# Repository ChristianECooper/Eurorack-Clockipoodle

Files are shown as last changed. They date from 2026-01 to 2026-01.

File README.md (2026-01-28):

### Clockipoodle
Clockipoodle is a clock module designed for use in a Eurorack modular synthesizer.

It's based on an Arduino nano, driving a Darlington Array, the UI is:
- a 128x64 pixel SSD1306 display,
- a switched rotary encoder,
- 2 x momentary buttons
- 6 x 3.5mm standard jacks

As of version 1.1 it supports the following options:
1. Direct setting of BPM via a rotary encoder.
2. Indirect setting of the BPM, using the rotary encoder to set, then pressing the encoder to apply.
3. Four additional outputs labelled A through to D that can be a multuplied, divided, duplicate or a disabled copy of the main clock.
4. Tap to set BPM.
5. Adjustable pulse width.
6. Play/Pause.
7. Reset the various outputs to be in sync again.

There is also an unused input currenly labeled as 'CV IN' and and associated LED, which may become a Clock in or CV input that drives a parameter (or parameters) to be later defined.
The current design is limited to 0-5V so could only really increase the tempo, so the next iteration is likely to support -5 to +5v so that decreasing tempo from a CV input is an option.
In the meantime I'm considering using the CV input to adjust a swing component of the beat.

All input and output jacks are protected against over voltage and negative voltages for safety.

This is my first stab at a module design, comments are welcome.

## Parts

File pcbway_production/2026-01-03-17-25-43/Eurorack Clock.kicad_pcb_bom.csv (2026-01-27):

Designator | Quantity | Value | Footprint | Package | MPN | DNP | Mount_Type | Description | Sim.Pins
A1 | 1 | Arduino_Nano_v3.x | Arduino_Nano |  |  |  | tht | Arduino Nano v3.x
C1 | 1 | 0.1u | CP_Radial_D10.0mm_P2.50mm |  |  |  | tht | Polarized capacitor
D1, D10, D11, D12, D13, D14, D2, D5, D6, D7, D8, D9 | 12 | BAT43 | D_DO-35_SOD27_P2.54mm_Vertical_KathodeUp |  |  |  | tht | 30V 0.2A Small Signal Schottky Diode, DO-35
D15, D16, D17, D18, D19, D20 | 6 | LED | LED_D3.0mm_FlatTop |  |  |  | tht | Light emitting diode | 1=K 2=A
DS1 | 1 | ~ | SSD1306_0.96_I2C_Display |  |  |  | smt
J1 | 1 | Conn_01x10_Pin | PinHeader_1x10_P2.54mm_Vertical |  |  |  | tht | Generic connector, single row, 01x10, script generated
J10 | 1 | CLK/16 | Jack_3.5mm_QingPu_WQP-PJ398SM_Vertical_CircularHoles |  |  |  | tht | Audio Jack, 2 Poles (Mono / TS)
J11 | 1 | Conn_02x08_Row_Letter_Last | IDC-Header_2x08_P2.54mm_Vertical_Eurorack |  |  |  | tht | Generic connector, double row, 02x08, row letter last pin numbering scheme (pin number consists of a letter for the row and a number for the pin index in this row. 1a, ..., Na; 1b, ..., Nb)), script generated (kicad-library-utils/schlib/autogen/connector/)
J12 | 1 | Conn_01x02_Pin | PinHeader_1x02_P2.54mm_Vertical |  |  |  | tht | Generic connector, single row, 01x02, script generated
J13 | 1 | Conn_01x02_Socket | PinSocket_1x02_P2.54mm_Vertical |  |  |  | tht | Generic connector, single row, 01x02, script generated
J2 | 1 | Conn_01x08_Pin | PinHeader_1x08_P2.54mm_Vertical |  |  |  | tht | Generic connector, single row, 01x08, script generated
J3 | 1 | Clock In | Jack_3.5mm_QingPu_WQP-PJ398SM_Vertical_CircularHoles |  |  |  | tht | Audio Jack, 2 Poles (Mono / TS)
J4 | 1 | Conn_01x10_Socket | PinSocket_1x10_P2.54mm_Vertical |  |  |  | tht | Generic connector, single row, 01x10, script generated
J5 | 1 | Conn_01x08_Pin | PinSocket_1x08_P2.54mm_Vertical |  |  |  | tht | Generic connector, single row, 01x08, script generated
J6 | 1 | CLK | Jack_3.5mm_QingPu_WQP-PJ398SM_Vertical_CircularHoles |  |  |  | tht | Audio Jack, 2 Poles (Mono / TS)
J7 | 1 | CLK/2 | Jack_3.5mm_QingPu_WQP-PJ398SM_Vertical_CircularHoles |  |  |  | tht | Audio Jack, 2 Poles (Mono / TS)
J8 | 1 | CLK/4 | Jack_3.5mm_QingPu_WQP-PJ398SM_Vertical_CircularHoles |  |  |  | tht | Audio Jack, 2 Poles (Mono / TS)
J9 | 1 | CLK/8 | Jack_3.5mm_QingPu_WQP-PJ398SM_Vertical_CircularHoles |  |  |  | tht | Audio Jack, 2 Poles (Mono / TS)
R1 | 1 | 470R | R_Axial_DIN0204_L3.6mm_D1.6mm_P2.54mm_Vertical |  |  |  | tht | Resistor
R10, R11, R12, R13, R8, R9 | 6 | 100R | R_Axial_DIN0204_L3.6mm_D1.6mm_P2.54mm_Vertical |  |  |  | tht | Resistor
R2, R3, R4, R5, R6 | 5 | 1K | R_Axial_DIN0204_L3.6mm_D1.6mm_P2.54mm_Vertical |  |  |  | tht | Resistor
REF_Reset, REF_Run, Reset, Run | 4 | PinHeader_1x02_P2.54mm_Vertical | PinHeader_1x02_P2.54mm_Vertical |  |  |  | tht
REF_Stand1, REF_Stand1A, REF_Stand2, REF_Stand2A | 4 | PinHeader_1x01_P2.54mm_Vertical | PinHeader_1x01_P2.54mm_Vertical |  |  |  | tht
SW1 | 1 | RotaryEncoder_DualWithSwitch | RotaryEncoder_Vertical_H25mm_Dual_PushButton |  |  |  | smt | Rotary encoder, dual channel, incremental quadrate outputs, with switch
SW2 | 1 | Run/Stop | SW_PUSH_6mm_H4.3mm |  |  |  | tht | Single Pole Single Throw (SPST) switch
SW3 | 1 | Reset | SW_PUSH_6mm_H4.3mm |  |  |  | tht | Single Pole Single Throw (SPST) switch
U1 | 1 | ULN2003 | DIP-16_W7.62mm_Socket |  |  |  | tht | High Voltage, High Current Darlington Transistor Arrays, SOIC16/SOIC16W/DIP16/TSSOP16
U6 | 1 | L7805 | TO-220-3_Vertical |  |  |  | tht | Positive 1.5A 35V Linear Regulator, Fixed Output 5V, TO-220/TO-263/TO-252

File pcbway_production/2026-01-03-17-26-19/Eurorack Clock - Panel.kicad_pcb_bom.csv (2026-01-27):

Designator | Quantity | Value | Footprint | Package | MPN | DNP | Mount_Type | Sim.Pins
6H | 1 | MountingHoles_6H_Panel | MountingHoles_6H_Panel |  |  |  | smt
D15X, D16X, D17X, D18X, D19X, D20X | 6 | LED | MountingHole_3.1mm_LED_D3.0mm_FlatTop |  |  |  | tht | 1=K 2=A
DS1X | 1 | ~ | MoutingHole_24x12mm_SSD1306_0.96_I2C_Display |  |  |  | smt
J10X | 1 | CLK/16 | MountingHole_6.0mm_Jack_3.5mm_QingPu_Vertical |  |  |  | tht
J3X | 1 | Clock In | MountingHole_6.0mm_Jack_3.5mm_QingPu_Vertical |  |  |  | tht
J6X | 1 | CLK | MountingHole_6.0mm_Jack_3.5mm_QingPu_Vertical |  |  |  | tht
J7X | 1 | CLK/2 | MountingHole_6.0mm_Jack_3.5mm_QingPu_Vertical |  |  |  | tht
J8X | 1 | CLK/4 | MountingHole_6.0mm_Jack_3.5mm_QingPu_Vertical |  |  |  | tht
J9X | 1 | CLK/8 | MountingHole_6.0mm_Jack_3.5mm_QingPu_Vertical |  |  |  | tht
SW1X | 1 | RotaryEncoder_DualWithSwitch | MountingHole_7.1mm_RotaryEncoder_Vertical_H25mm_Dual_PushButton |  |  |  | smt
SW2X | 1 | Run/Stop | MountingHole_8.1mm_SW_PUSH_6x6mm |  |  |  | tht
SW3X | 1 | Reset | MountingHole_8.1mm_SW_PUSH_6x6mm |  |  |  | tht

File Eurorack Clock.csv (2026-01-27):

Reference | Qty | Value | DNP | Exclude from BOM | Exclude from Board | Footprint | Datasheet
A1 | 1 | Arduino_Nano_v3.x |  |  |  | Module:Arduino_Nano | http://www.mouser.com/pdfdocs/Gravitech_Arduino_Nano3_0.pdf
C1 | 1 | 0.1u |  |  |  | Capacitor_THT:CP_Radial_D10.0mm_P2.50mm | ~
D1,D2,D5,D6,D7,D8,D9,D10,D11,D12,D13,D14 | 12 | BAT43 |  |  |  | Diode_THT:D_DO-35_SOD27_P2.54mm_Vertical_KathodeUp | http://www.vishay.com/docs/85660/bat42.pdf
D15,D16,D17,D18,D19,D20 | 6 | LED |  |  |  | LED_THT:LED_D3.0mm_FlatTop | ~
DS1 | 1 | ~ |  |  |  | Displays:SSD1306_0.96_I2C_Display
J1 | 1 | Conn_01x10_Pin |  |  |  | Connector_PinHeader_2.54mm:PinHeader_1x10_P2.54mm_Vertical | ~
J2 | 1 | Conn_01x08_Pin |  |  |  | Connector_PinHeader_2.54mm:PinHeader_1x08_P2.54mm_Vertical | ~
J3 | 1 | Clock In |  |  |  | Connector_Audio:Jack_3.5mm_QingPu_WQP-PJ398SM_Vertical_CircularHoles | ~
J4 | 1 | Conn_01x10_Socket |  |  |  | Connector_PinSocket_2.54mm:PinSocket_1x10_P2.54mm_Vertical | ~
J5 | 1 | Conn_01x08_Pin |  |  |  | Connector_PinSocket_2.54mm:PinSocket_1x08_P2.54mm_Vertical | ~
J6 | 1 | CLK |  |  |  | Connector_Audio:Jack_3.5mm_QingPu_WQP-PJ398SM_Vertical_CircularHoles | ~
J7 | 1 | CLK/2 |  |  |  | Connector_Audio:Jack_3.5mm_QingPu_WQP-PJ398SM_Vertical_CircularHoles | ~
J8 | 1 | CLK/4 |  |  |  | Connector_Audio:Jack_3.5mm_QingPu_WQP-PJ398SM_Vertical_CircularHoles | ~
J9 | 1 | CLK/8 |  |  |  | Connector_Audio:Jack_3.5mm_QingPu_WQP-PJ398SM_Vertical_CircularHoles | ~
J10 | 1 | CLK/16 |  |  |  | Connector_Audio:Jack_3.5mm_QingPu_WQP-PJ398SM_Vertical_CircularHoles | ~
J11 | 1 | Conn_02x08_Row_Letter_Last |  |  |  | Eurorack Switches:IDC-Header_2x08_P2.54mm_Vertical_Eurorack | ~
J12 | 1 | Conn_01x02_Pin |  |  |  | Connector_PinHeader_2.54mm:PinHeader_1x02_P2.54mm_Vertical | ~
J13 | 1 | Conn_01x02_Socket |  |  |  | Connector_PinSocket_2.54mm:PinSocket_1x02_P2.54mm_Vertical | ~
JP1 | 1 | 5v/12v power source |  | Excluded from BOM |  | Connector_PinHeader_2.54mm:PinHeader_1x03_P2.54mm_Vertical | ~
JP2 | 1 | 5V Source |  | Excluded from BOM |  | Jumper:SolderJumper-2_P1.3mm_Open_Pad1.0x1.5mm | ~
JP3 | 1 | 12V Source |  | Excluded from BOM |  | Jumper:SolderJumper-2_P1.3mm_Open_Pad1.0x1.5mm | ~
R1 | 1 | 470R |  |  |  | Resistor_THT:R_Axial_DIN0204_L3.6mm_D1.6mm_P2.54mm_Vertical | ~
R2,R3,R4,R5,R6 | 5 | 1K |  |  |  | Resistor_THT:R_Axial_DIN0204_L3.6mm_D1.6mm_P2.54mm_Vertical | ~
R8,R9,R10,R11,R12,R13 | 6 | 100R |  |  |  | Resistor_THT:R_Axial_DIN0204_L3.6mm_D1.6mm_P2.54mm_Vertical | ~
SW1 | 1 | RotaryEncoder_DualWithSwitch |  |  |  | Rotary Encoders:RotaryEncoder_Vertical_H25mm_Dual_PushButton | ~
SW2 | 1 | Run/Stop |  |  |  | Button_Switch_THT:SW_PUSH_6mm_H4.3mm | ~
SW3 | 1 | Reset |  |  |  | Button_Switch_THT:SW_PUSH_6mm_H4.3mm | ~
U1 | 1 | ULN2003 |  |  |  | Package_DIP:DIP-16_W7.62mm_Socket | http://www.ti.com/lit/ds/symlink/uln2003a.pdf
U6 | 1 | L7805 |  |  |  | Package_TO_SOT_THT:TO-220-3_Vertical | http://www.st.com/content/ccc/resource/technical/document/datasheet/41/4f/b3/b0/12/d4/47/88/CD00000444.pdf/files/CD00000444.pdf/jcr:content/translations/en.CD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

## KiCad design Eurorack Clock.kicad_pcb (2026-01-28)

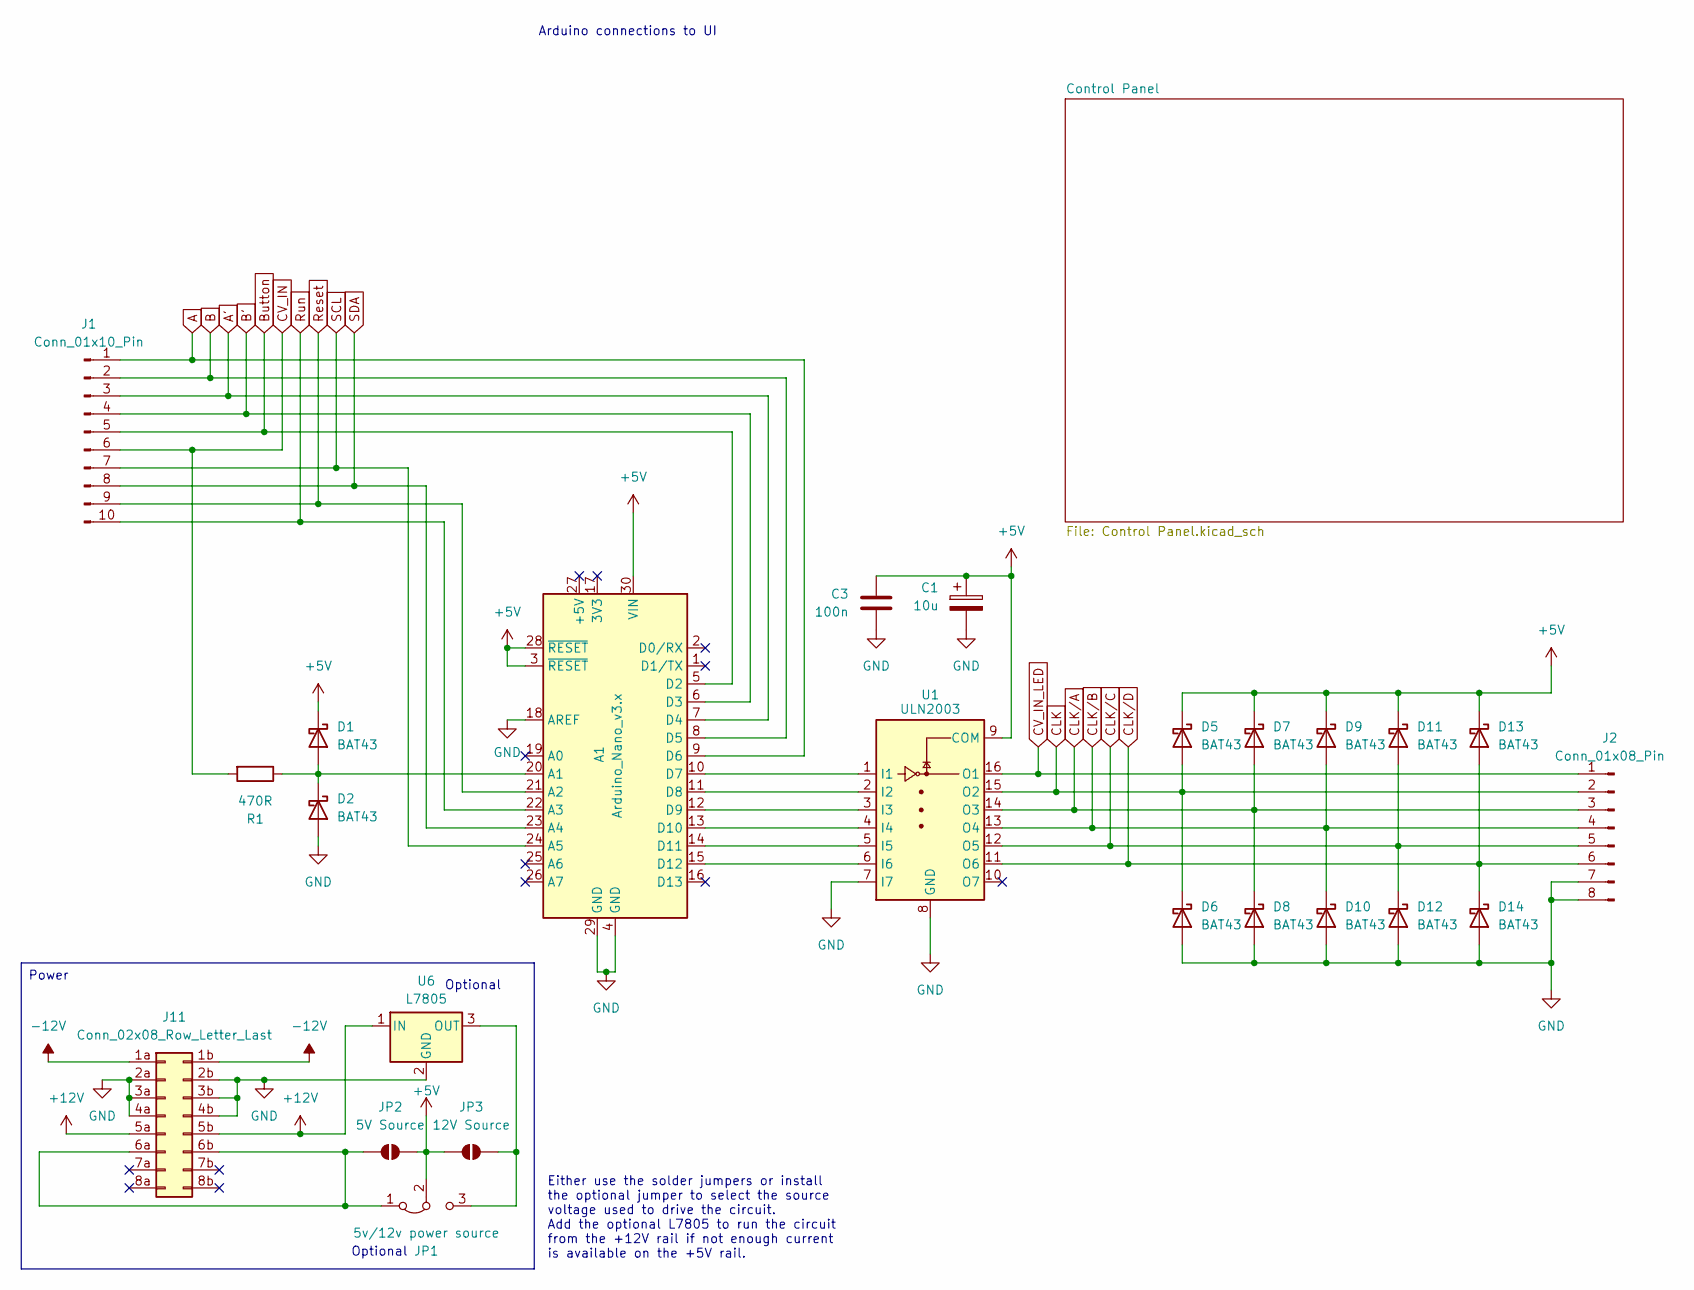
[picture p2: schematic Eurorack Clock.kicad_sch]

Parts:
A1: Arduino_Nano_v3.x; Arduino_Nano
C1: 10u; CP_Radial_D5.0mm_P2.50mm
C3: 100n; C_Disc_D4.7mm_W2.5mm_P5.00mm
D1, D2, D5, D6, D7, D8, D9, D10, D11, D12, D13, D14: BAT43; D_DO-35_SOD27_P2.54mm_Vertical_KathodeUp
J1: Conn_01x10_Pin; PinHeader_1x10_P2.54mm_Vertical
J2: Conn_01x08_Pin; PinHeader_1x08_P2.54mm_Vertical
J11: Conn_02x08_Row_Letter_Last; IDC-Header_2x08_P2.54mm_Vertical_Eurorack
JP1: 5v/12v power source; PinHeader_1x03_P2.54mm_Vertical
JP2: 5V Source; SolderJumper-2_P1.3mm_Open_Pad1.0x1.5mm
JP3: 12V Source; SolderJumper-2_P1.3mm_Open_Pad1.0x1.5mm
R1: 470R; R_Axial_DIN0204_L3.6mm_D1.6mm_P2.54mm_Vertical
U1: ULN2003; DIP-16_W7.62mm_Socket
U6: L7805; TO-220-3_Vertical

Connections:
+5V: A1.3 (~RESET), A1.28 (~RESET), A1.30 (VIN), C1.1, C3.1, D1.1 (K), D5.1 (K), D7.1 (K), D9.1 (K), D11.1 (K), D13.1 (K), JP1.2 (C), JP2.2 (B), JP3.1 (A), U1.9 (COM); also elsewhere on the board
+12V: J11.5a, J11.5b, U6.1 (IN)
-12V: J11.1a, J11.1b
A: A1.9 (D6), J1.1; also elsewhere on the board
A': A1.7 (D4), J1.3; also elsewhere on the board
B: A1.8 (D5), J1.2; also elsewhere on the board
B': A1.6 (D3), J1.4; also elsewhere on the board
Button: A1.5 (D2), J1.5; also elsewhere on the board
CLK: D5.2 (A), D6.1 (K), J2.2, U1.15 (O2); also elsewhere on the board
CLK/A: D7.2 (A), D8.1 (K), J2.3, U1.14 (O3); also elsewhere on the board
CLK/B: D9.2 (A), D10.1 (K), J2.4, U1.13 (O4); also elsewhere on the board
CLK/C: D11.2 (A), D12.1 (K), J2.5, U1.12 (O5); also elsewhere on the board
CLK/D: D13.2 (A), D14.1 (K), J2.6, U1.11 (O6); also elsewhere on the board
CV_IN: J1.6, R1.2; also elsewhere on the board
CV_IN_LED: J2.1, U1.16 (O1); also elsewhere on the board
GND: A1.4 (GND), A1.18 (AREF), A1.29 (GND), C1.2, C3.2, D2.2 (A), D6.2 (A), D8.2 (A), D10.2 (A), D12.2 (A), D14.2 (A), J2.7, J2.8, J11.2a, J11.2b, J11.3a, J11.3b, J11.4a, J11.4b, U1.7 (I7), U1.8 (GND), U6.2 (GND); also elsewhere on the board
unnamed: A1.20 (A1), D1.2 (A), D2.1 (K), R1.1
unnamed: A1.10 (D7), U1.1 (I1)
unnamed: A1.11 (D8), U1.2 (I2)
unnamed: A1.12 (D9), U1.3 (I3)
unnamed: A1.13 (D10), U1.4 (I4)
unnamed: A1.14 (D11), U1.5 (I5)
unnamed: A1.15 (D12), U1.6 (I6)
unnamed: J11.6a, J11.6b, JP1.1 (A), JP2.1 (A)
unnamed: JP1.3 (B), JP3.2 (B), U6.3 (OUT)
Reset: A1.21 (A2), J1.9; also elsewhere on the board
Run: A1.22 (A3), J1.10; also elsewhere on the board
SCL: A1.24 (A5), J1.7; also elsewhere on the board
SDA: A1.23 (A4), J1.8; also elsewhere on the board

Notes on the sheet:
Either use the solder jumpers or install the optional jumper to select the source voltage used to drive the circuit. Add the optional L7805 to run the circuit from the +12V rail if not enough current is available on the +5V rail.
Optional
Arduino connections to UI
Power

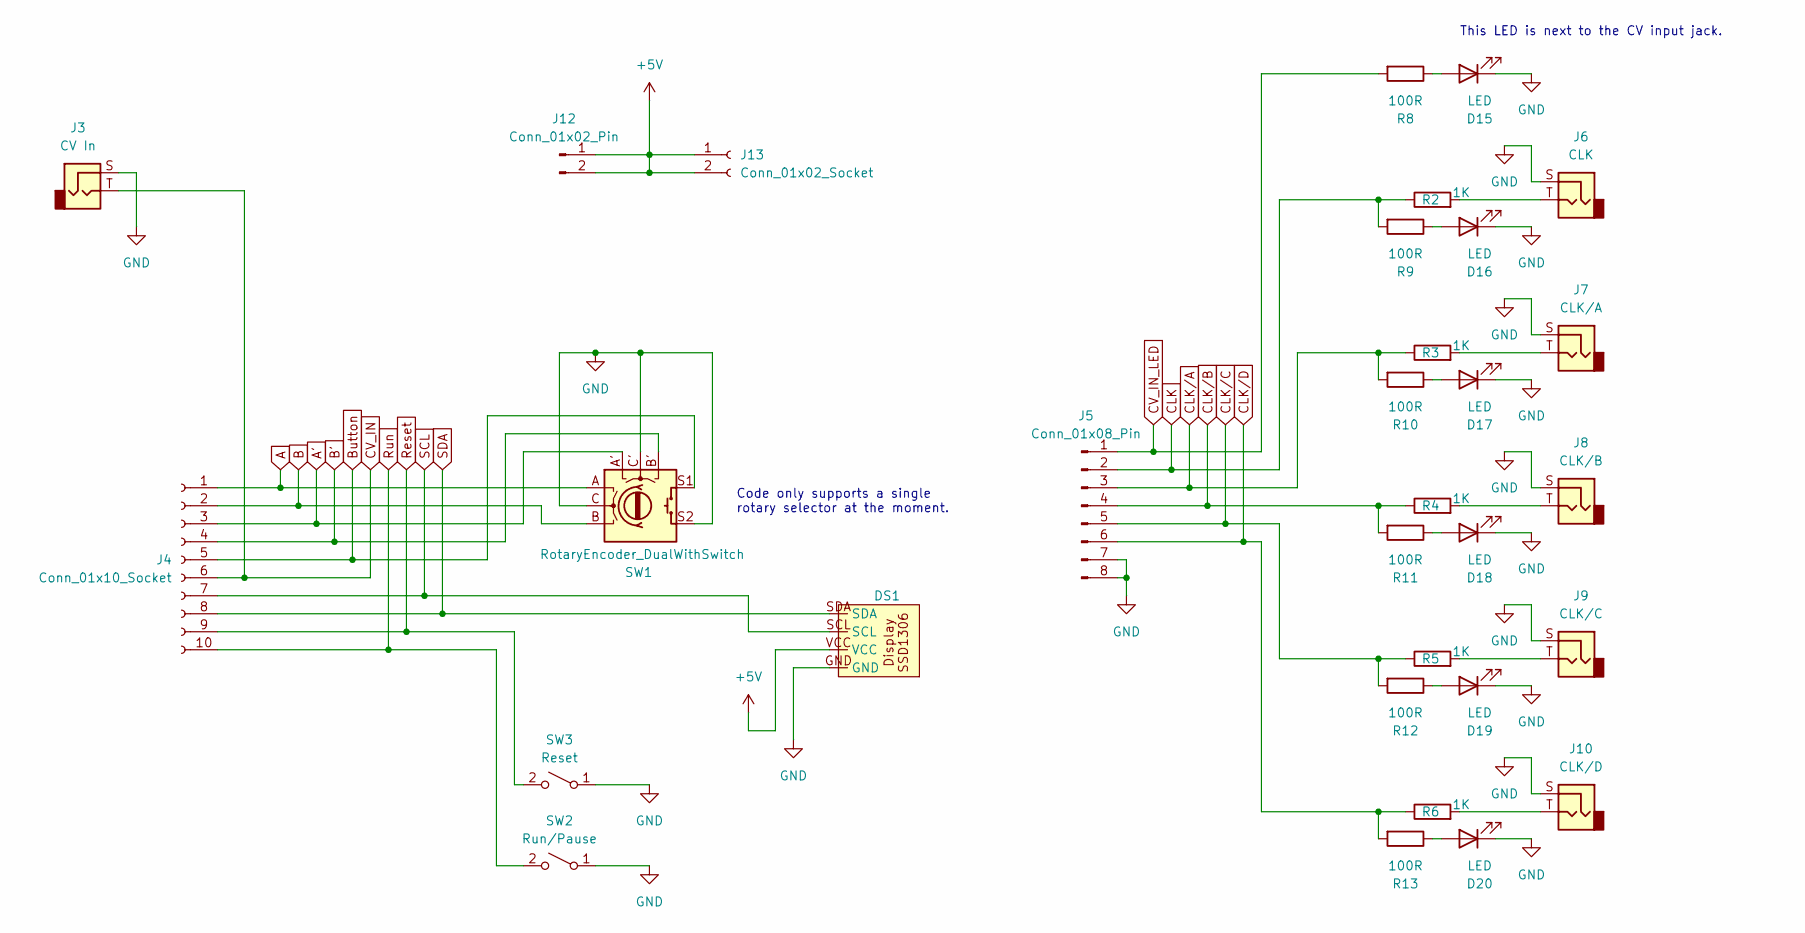
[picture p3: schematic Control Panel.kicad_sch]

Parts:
D15, D16, D17, D18, D19, D20: LED; LED_D3.0mm_FlatTop
DS1: SSD1306_0.96_I2C_Display
J3: CV In; Jack_3.5mm_QingPu_WQP-PJ398SM_Vertical_CircularHoles
J4: Conn_01x10_Socket; PinSocket_1x10_P2.54mm_Vertical
J5: Conn_01x08_Pin; PinSocket_1x08_P2.54mm_Vertical
J6: CLK; Jack_3.5mm_QingPu_WQP-PJ398SM_Vertical_CircularHoles
J7: CLK/A; Jack_3.5mm_QingPu_WQP-PJ398SM_Vertical_CircularHoles
J8: CLK/B; Jack_3.5mm_QingPu_WQP-PJ398SM_Vertical_CircularHoles
J9: CLK/C; Jack_3.5mm_QingPu_WQP-PJ398SM_Vertical_CircularHoles
J10: CLK/D; Jack_3.5mm_QingPu_WQP-PJ398SM_Vertical_CircularHoles
J12: Conn_01x02_Pin; PinHeader_1x02_P2.54mm_Vertical
J13: Conn_01x02_Socket; PinSocket_1x02_P2.54mm_Vertical
R2, R3, R4, R5, R6: 1K; R_Axial_DIN0204_L3.6mm_D1.6mm_P2.54mm_Vertical
R8, R9, R10, R11, R12, R13: 100R; R_Axial_DIN0204_L3.6mm_D1.6mm_P2.54mm_Vertical
SW1: RotaryEncoder_DualWithSwitch; RotaryEncoder_Vertical_H25mm_Dual_PushButton
SW2: Run/Pause; SW_PUSH_6mm_H4.3mm
SW3: Reset; SW_PUSH_6mm_H4.3mm

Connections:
+5V: DS1.VCC, J12.1, J12.2, J13.1, J13.2; also elsewhere on the board
A: J4.1, SW1.A; also elsewhere on the board
A': J4.3, SW1.A'; also elsewhere on the board
B: J4.2, SW1.B; also elsewhere on the board
B': J4.4, SW1.B'; also elsewhere on the board
Button: J4.5, SW1.S1; also elsewhere on the board
CLK: J5.2, R2.1, R9.2; also elsewhere on the board
CLK/A: J5.3, R3.1, R10.2; also elsewhere on the board
CLK/B: J5.4, R4.1, R11.2; also elsewhere on the board
CLK/C: J5.5, R5.1, R12.2; also elsewhere on the board
CLK/D: J5.6, R6.1, R13.2; also elsewhere on the board
CV_IN: J3.T, J4.6; also elsewhere on the board
CV_IN_LED: J5.1, R8.2; also elsewhere on the board
GND: D15.1 (K), D16.1 (K), D17.1 (K), D18.1 (K), D19.1 (K), D20.1 (K), DS1.GND, J3.S, J5.7, J5.8, J6.S, J7.S, J8.S, J9.S, J10.S, SW1.C, SW1.C', SW1.S2, SW2.1 (A), SW3.1 (A); also elsewhere on the board
unnamed: D15.2 (A), R8.1
unnamed: D16.2 (A), R9.1
unnamed: D17.2 (A), R10.1
unnamed: D18.2 (A), R11.1
unnamed: D19.2 (A), R12.1
unnamed: D20.2 (A), R13.1
unnamed: J6.T, R2.2
unnamed: J7.T, R3.2
unnamed: J8.T, R4.2
unnamed: J9.T, R5.2
unnamed: J10.T, R6.2
Reset: J4.9, SW3.2 (B); also elsewhere on the board
Run: J4.10, SW2.2 (B); also elsewhere on the board
SCL: DS1.SCL, J4.7; also elsewhere on the board
SDA: DS1.SDA, J4.8; also elsewhere on the board

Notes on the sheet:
Code only supports a single rotary selector at the moment.
This LED is next to the CV input jack.

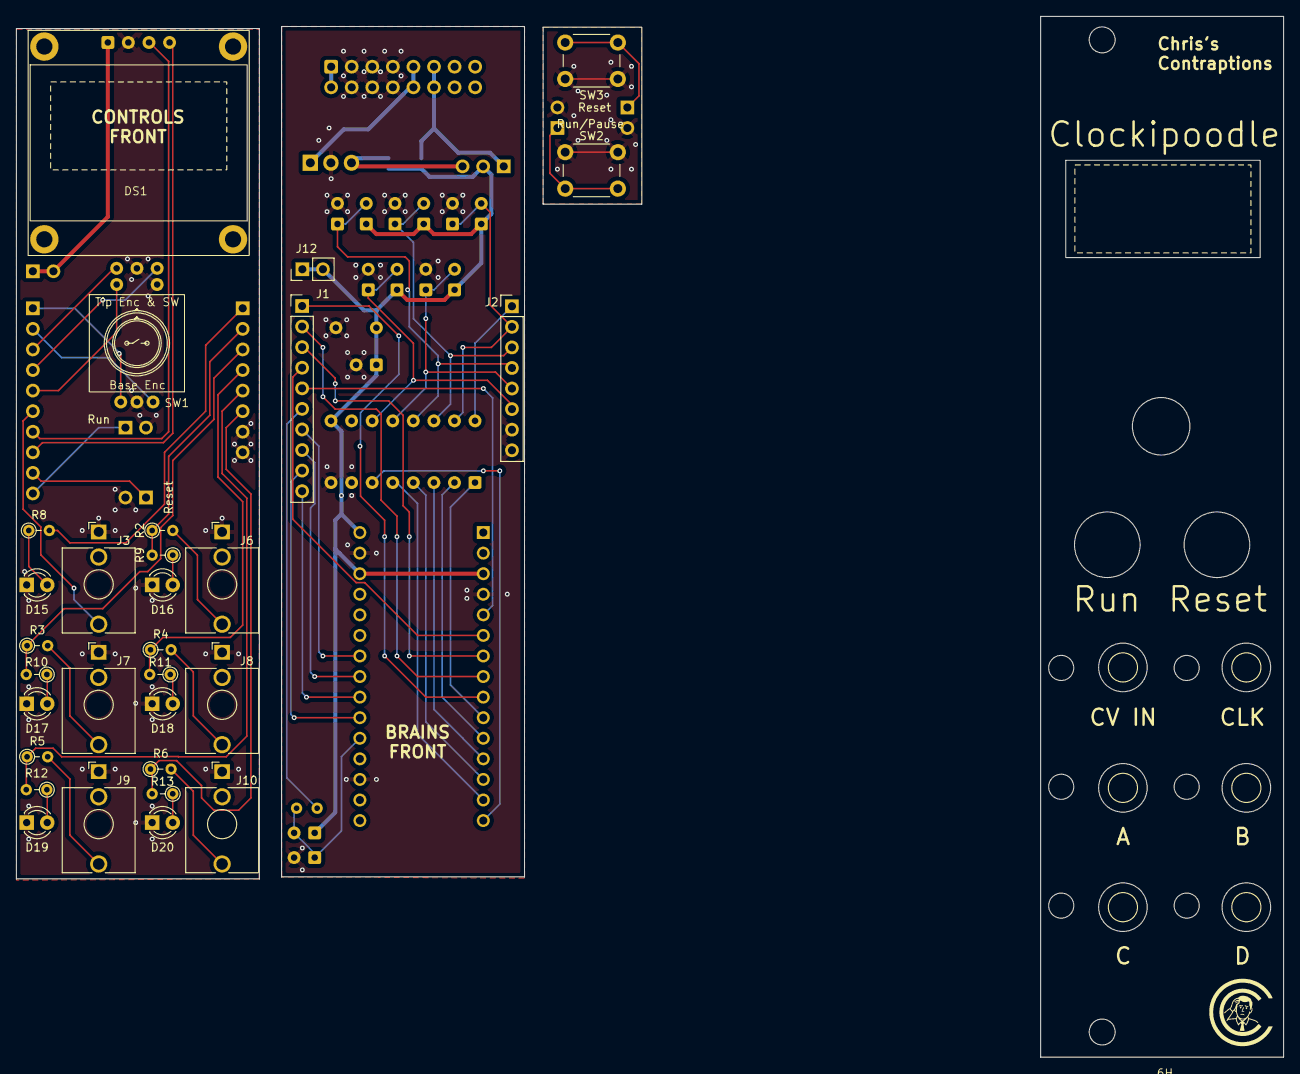
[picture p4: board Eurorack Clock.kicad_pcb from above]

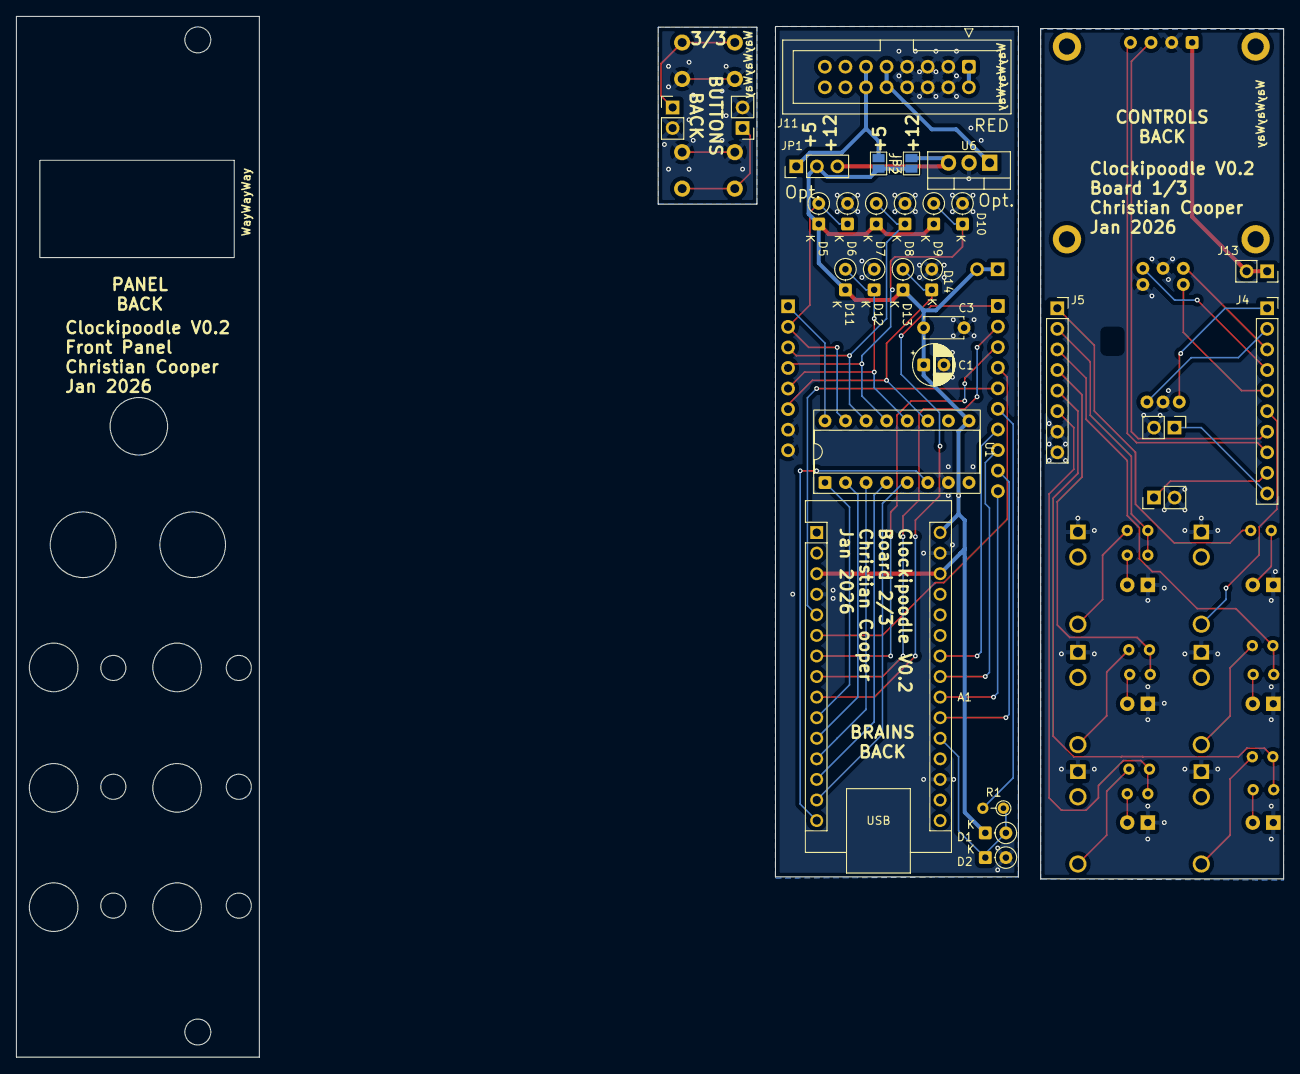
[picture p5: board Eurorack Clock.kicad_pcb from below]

Board: 2 copper layers, 156.5 x 128.5 mm, 77 parts (29 on the bottom side), 40 nets.

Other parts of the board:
6H: MountingHoles_6H_Panel
D15X, D16X, D17X, D18X, D19X, D20X: LED; MountingHole_3.1mm_LED_D3.0mm_FlatTop
DS1X: MoutingHole_24x12mm_SSD1306_0.96_I2C_Display
J3X: CV IN; MountingHole_6.0mm_Jack_3.5mm_QingPu_Vertical
J6X: CLK; MountingHole_6.0mm_Jack_3.5mm_QingPu_Vertical
J7X: CLK/2; MountingHole_6.0mm_Jack_3.5mm_QingPu_Vertical
J8X: CLK/4; MountingHole_6.0mm_Jack_3.5mm_QingPu_Vertical
J9X: CLK/8; MountingHole_6.0mm_Jack_3.5mm_QingPu_Vertical
J10X: CLK/16; MountingHole_6.0mm_Jack_3.5mm_QingPu_Vertical
LOGO***: LOGO; cc_logo
REF_Reset: PinHeader_1x02_P2.54mm_Vertical
REF_Run: PinHeader_1x02_P2.54mm_Vertical
Reset: PinHeader_1x02_P2.54mm_Vertical
Run: PinHeader_1x02_P2.54mm_Vertical
SW1X: RotaryEncoder_DualWithSwitch; MountingHole_7.1mm_RotaryEncoder_Vertical_H25mm_Dual_PushBu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
SW2X: Run/Stop; MountingHole_8.1mm_SW_PUSH_6x6mm
SW3X: Reset; MountingHole_8.1mm_SW_PUSH_6x6mm

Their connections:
GND: REF_Reset.2, REF_Run.2, Reset.2, Run.2; also elsewhere on the board
Reset: REF_Reset.1, Reset.1; also elsewhere on the board
Run: REF_Run.1, Run.1; also elsewhere on the board

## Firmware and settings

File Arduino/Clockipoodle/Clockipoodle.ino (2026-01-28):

/*
TODO:
-- 0. Fix timing bugs!
-- 1. Setting pulse width
-- 2. Setting for direct BPM mode - no click to apply new BPM
-- 3. Reset button to revert in menu system
-- 4. Display channel information on home screen
-- 5. Display 'BPM' on home screen and align big text at 2 chars
-- 6. Fast rotation increments step size on bpm selection
-- 7. Implement start/stop button
-- 8. Implement facory reset
9. Custom font?
10. Clock in & LED
-- 11. Tap to set BPM
*/

// Display
#include <SPI.h>
#include <Wire.h>
#include <Adafruit_GFX.h>
#include <Adafruit_SSD1306.h>

#include <EEPROM.h>

//////////////////////////////////////////////////////////////////////
// Logging
//////////////////////////////////////////////////////////////////////
//***************************************************************
#define DEBUG  // if this line is NOT commented, LO and LOG macros will be included in the sketch

#ifdef DEBUG
#define LO(args...)  Serial.print(args)
#define LOG(args...)  Serial.println(args)

#else

#define LO(args...)
#define LOG(args...)
#endif


//////////////////////////////////////////////////////////////////////
// Constants
//////////////////////////////////////////////////////////////////////
#define VERSION "V1.1"

// IO state management (internal pull-ups used, so values are inverted)
#define PRESSED LOW
#define RELEASED HIGH

// EEPROM
// Magic number for EEPROM initialisation detection
#define MAGIC_NUMBER 0xCC
#define EEPROM_BASE_ADDRESS 16

// Display
#define SCREEN_WIDTH 128 // OLED display width, in pixels
#define SCREEN_HEIGHT 64 // OLED display height, in pixels
#define OLED_RESET     -1 // Reset pin # (or -1 if sharing Arduino reset pin)
#define SCREEN_ADDRESS 0x3C ///< See datasheet for Address; 0x3D for 128x64, 0x3C for 128x32

#define CHAR_HEIGHT 8
#define CHAR_WIDTH 8

// --- Inputs ---
// Rotary encoder
#define ROTARY_PINA	6
#define ROTARY_PINB	5
#define BUTTON_PIN	2

#define CLOCK_IN_PIN A1
#define RESET_PIN    A2
#define RUN_PIN      A3

// --- Outputs ---
#define CLOCK_IN_LED_PIN   7
#define CLOCK_PIN          8
#define CLOCK_CUSTOM_1_PIN 9
#define CLOCK_CUSTOM_2_PIN 10
#define CLOCK_CUSTOM_3_PIN 11
#define CLOCK_CUSTOM_4_PIN 12

// Clock specification
#define DEFAULT_PULSE_WIDTH 10 // ms

// Update mode
#define DEFAULT_DIRECT_BPM_MODE false

// Config layout
#define CONFIG_PULSE_WIDTH_LINE 4
#define CONFIG_DIRECT_BPM_LINE 5
#define CONFIG_TAP_LINE 6
#define CONFIG_RETURN_LINE 7

//////////////////////////////////////////////////////////////////////
// Structs
//////////////////////////////////////////////////////////////////////
struct customClock{
  char clockType; // Limited to 'X'=OFF, '/'=DIV, '='=DUPE, '*'=MUL
  int clockCount; // Indicates factor used for '*' and '/' clock types
};

//////////////////////////////////////////////////////////////////////
// Enums
//////////////////////////////////////////////////////////////////////
// State machine
// State for main overall mode
enum DisplayMode{RUN, CONFIG, TAP};
// Sub-states for CONFIG mode
enum ConfigMode{SELECT_LINE, SELECT_VALUE, UPDATE_PULSE_WIDTH, UPDATE_DIRECT_BPM_MODE, UPDATE_VALUE};
// Sub-sub-states for CONFIG/SELECT_VALUE
enum ConfigOption{FUNCTION, VALUE, LINE_RETURN};

// Lines visible on the config screen
enum ConfigLine{A, B, C, D, PULSE_WIDTH, BPM_DIRECT, TAP_MODE, RETURN};

//////////////////////////////////////////////////////////////////////
// Constants
//////////////////////////////////////////////////////////////////////
const int CUSTOM_CLOCK_PINS[] = {CLOCK_CUSTOM_1_PIN, CLOCK_CUSTOM_2_PIN, CLOCK_CUSTOM_3_PIN, CLOCK_CUSTOM_4_PIN};
const char CHANNEL_NAMES[] = "ABCD";
const int MIN_BPM = 40;
const int MAX_BPM = 260;

//////////////////////////////////////////////////////////////////////
// Variables
//////////////////////////////////////////////////////////////////////
// Construct display
Adafruit_SSD1306 display(SCREEN_WIDTH, SCREEN_HEIGHT, &Wire, OLED_RESET);

// Live config
bool directBpmMode = DEFAULT_DIRECT_BPM_MODE;
int pulseWidth = DEFAULT_PULSE_WIDTH;
customClock customClocks[] = {
  {'/', 4},
  {'/', 2},
  {'*', 2},
  {'*', 4},
};

// All on internal pull up resistors
bool rotaryAState = RELEASED;
bool rotaryBState = RELEASED;
bool rotaryButtonState = RELEASED;
bool resetState = RELEASED;
bool runState = RELEASED;

// State change flags
bool rotaryAStateUpdated = false;
bool rotaryBStateUpdated = false;
bool rotaryButtonStateUpdated = false;
bool resetStateUpdated = false;
bool runStateUpdated = false;

// State change detection
bool lastRotaryAState = RELEASED;
bool lastRotaryButtonState = RELEASED;
bool lastResetState = RELEASED;
bool lastRunState = RELEASED;

// BPM management
int bpm = 120;
int nextBpm = bpm;

// Event management
// Tracker of current beat in main clock for DIV cycles
volatile unsigned long tick = 0;
volatile unsigned long now = millis();
volatile unsigned long mainClockDelayMs = (long) (60.0 / bpm * 1000);
volatile unsigned long nextMainClockStart = now + mainClockDelayMs;
volatile unsigned long nextMainClockFinish = nextMainClockStart + pulseWidth;

bool customClockEnabled[] = {0, 0, 0, 0};
volatile unsigned long customClockDelay[] = {0, 0, 0, 0};
volatile unsigned long nextCustomClockStart[] = {0, 0, 0, 0};
volatile unsigned long nextCustomClockFinish[] = {0, 0, 0, 0};

// Tap mode, record of timestamps for taps
long taps[] = {0, 0, 0, 0};

// Start/Stop state
bool running = true;

// UI
bool updateDisplay = true;
// Default starting position of state machine
DisplayMode displayMode = RUN;

// UI - Config screen tracking
ConfigMode configMode = SELECT_LINE; 
ConfigLine configLine = A;
ConfigOption configOption = FUNCTION;
bool configOptionSelected = false;

//////////////////////////////////////////////////////////////////////
// Utility functions
//////////////////////////////////////////////////////////////////////
/**
  A version of constrain that wraps values around if they exceed the limits
*/
static byte wrap(int value, byte low, byte high) {
  if (value < low) return high;
  if (value > high) return low;
  return value;
}

//////////////////////////////////////////////////////////////////////
// Event functions
//////////////////////////////////////////////////////////////////////
/**
  Convert BPM and various custom clock mutiplies to durations in milliseconds
*/
static void calculateAllClockDelays() {
  mainClockDelayMs = (long) (60.0 / bpm * 1000.0);
  for (int i=0; i < 4; i++) {
    if (customClocks[i].clockType == '/') {
      customClockDelay[i] = mainClockDelayMs * customClocks[i].clockCount;
    } else if (customClocks[i].clockType == '*') {
      customClockDelay[i] = (long) (mainClockDelayMs / customClocks[i].clockCount);
    } else {
      // Not enabled
      customClockDelay[i] = 0;
    }
  }
}

/**
  Set the next start time for any of the clocks.
  If allClocks is false, then customCLockIndex of -1 means main clock
  If initialising is true all the clocks are reset to start from now
  If restarting is true (only valid for custom clocks), this indicates that a clock has moved out of its OFF state and is now running again
*/
static void updateNextStartTime(bool allClocks=false, int customClockIndex=-1, bool initialising=false, bool restarting=false) {
  if (initialising) {
    // Set all clocks to trigger now, except DIV ones
    nextMainClockStart = now;
    for (byte i; i < 4; i++) {
      if (customClockEnabled[i]) {
        nextCustomClockStart[i] = nextMainClockStart; 
      }
      if (customClocks[i].clockType == '/') {
        nextCustomClockStart[i] += customClockDelay[i];
      }
    }
  }

  if (allClocks) {
    // Move all expired clock start times forward
    if (now > nextMainClockStart) {
      // Main clock
      nextMainClockStart += mainClockDelayMs;
    }
    for (byte i; i < 4; i++) {
      // Custom clocks
      if (customClockEnabled[i] && now > nextCustomClockStart[i]) {
        if (customClocks[i].clockType == '=' || customClocks[i].clockType == '*') {
          nextCustomClockStart[i] = nextMainClockStart; 
        } else {
          nextCustomClockStart[i] += customClockDelay[i]; 
        }
      }
    }

  } else {
    // Move a specific clock forward
    if (customClockIndex == -1) {
      // Main clock
      nextMainClockStart += mainClockDelayMs;
    } else {
      // Custom clock
      nextCustomClockStart[customClockIndex] += customClockDelay[customClockIndex];
      if (restarting) {
        nextCustomClockStart[customClockIndex] = nextMainClockStart + customClockDelay[customClockIndex];
        if (customClocks[customClockIndex].clockType == '/') {
          // Account for changes during the sequence.
          // E.g.: Post tick 3 of 4 when a DIV 4 is enabled, Remove the delay of the first 3 ticks from out next start.
          byte missedTicks = tick % customClocks[customClockIndex].clockCount;
          nextCustomClockStart[customClockIndex] -= missedTicks * mainClockDelayMs;
        }
      }
    }
  }
}

/**
  Shift the finish time for a puls on a clock
  If allClocks is false, then customCLockIndex of -1 means main clock
  If initialising is true all the clocks are reset to current start time plus pulse width
*/
static void updateNextFinishTime(bool allClocks=false, int customClockIndex=-1, bool initialising=false) {
  if (initialising || allClocks) {
    // Set all active clock's finish times
    nextMainClockFinish = nextMainClockStart + pulseWidth;
    for (byte i; i < 4; i++) {
      nextCustomClockFinish[i] = nextCustomClockStart[i] + pulseWidth; 
    }
  } else if (customClockIndex == -1) {
    // Update main clock
    nextMainClockFinish = nextMainClockStart + pulseWidth;
  } else {
    // Update selected custom clock
    nextCustomClockFinish[customClockIndex] = nextCustomClockStart[customClockIndex] + pulseWidth;
  }
}

//////////////////////////////////////////////////////////////////////
// UI drawing functions
//////////////////////////////////////////////////////////////////////
static void drawTriangle(byte rowOffset, byte colOffset, bool filled = false) {
  byte width = 7;
  byte height = 6;
  if (filled) {
    display.fillTriangle(
      colOffset, rowOffset, 
      colOffset + width, 4 + rowOffset, 
      colOffset, 8 + rowOffset, 
      SSD1306_WHITE
    );
  } else {
    display.drawTriangle(
      colOffset, rowOffset, 
      colOffset + width, 4 + rowOffset, 
      colOffset, 8 + rowOffset, 
      SSD1306_WHITE
    );
  }
}

static void drawReturnArrow(byte rowOffset, byte colOffset) {
  display.drawLine(
    colOffset, rowOffset, 
    colOffset, rowOffset + 4, 
    SSD1306_WHITE
  );
  display.drawLine(
    colOffset, rowOffset + 4, 
    colOffset - 4, rowOffset + 4, 
    SSD1306_WHITE
  );
  display.drawLine(
    colOffset - 4, rowOffset + 4, 
    colOffset - 2, rowOffset + 2, 
    SSD1306_WHITE
  );
  display.drawLine(
    colOffset - 4, rowOffset + 4, 
    colOffset - 2, rowOffset + 6, 
    SSD1306_WHITE
  );
}

/**
  Display the channel details of the selected channel
*/
static void prettyChannel(byte channel) {
  /*
  Dumps current state of channel to display at current cursor coordinates
  */
  String s = "";
  display.print(CHANNEL_NAMES[channel]);
  display.print(F(":"));
  switch (customClocks[channel].clockType) {
    case 'X':
      display.setTextColor(SSD1306_BLACK, SSD1306_WHITE); // Inverse text
      display.print(F(" OFF "));
      display.setTextColor(SSD1306_WHITE);
      display.print(F("  "));
      break;
    case '*':
      display.print(F("MUL/"));
      display.print(customClocks[channel].clockCount);
      if (customClocks[channel].clockCount < 10) {
        display.print(F("  "));
      } else if (customClocks[channel].clockCount < 100) {
        display.print(F(" "));
      }
      break;
    case '/':
      display.print(F("DIV/"));
      display.print(customClocks[channel].clockCount);
      if (customClocks[channel].clockCount < 10) {
        display.print(F("  "));
      } else if (customClocks[channel].clockCount < 100) {
        display.print(F(" "));
      }
      break;
    case '=':
      display.print(F("DUP    "));
      break;
  }
}

//////////////////////////////////////////////////////////////////////
// EEPROM management
//////////////////////////////////////////////////////////////////////
/**
  Looks for magic number at end of EEPROM, if it is not there clear the EEPROM, add the magic number and save the default values
*/
static void initEEPROM(bool force=false) {
  int temp = 0;
  EEPROM.get(EEPROM.length() - 1, temp);
  if (force || temp != MAGIC_NUMBER) {
    for (int i = 0 ; i < EEPROM.length() ; i++) {
      EEPROM.write(i, 0);
    }
    EEPROM.write(EEPROM.length() - 1, MAGIC_NUMBER);
    saveEEPROM();  
  }
}

/**
  Load previously saved contents of EEPROM into variables
*/
static void loadEEPROM() {
  // Increment address as you write
  int address = EEPROM_BASE_ADDRESS;

  EEPROM.get(address, directBpmMode);
  address += sizeof(directBpmMode);
  EEPROM.get(address, pulseWidth);
  address += sizeof(pulseWidth);
  EEPROM.get(address, bpm);
  address += sizeof(bpm);
  EEPROM.get(address, customClocks);
  address += sizeof(customClocks);

  normaliseLoadedValues();
}

/**
  Save current state of key variables into EEPROM so we can continue after a power outage
*/
static void saveEEPROM() {
  // Increment address as you read
  int address = EEPROM_BASE_ADDRESS;

  EEPROM.put(address, directBpmMode);
  address += sizeof(directBpmMode);
  EEPROM.put(address, pulseWidth);
  address += sizeof(pulseWidth);
  EEPROM.put(address, bpm);
  address += sizeof(bpm);
  EEPROM.put(address, customClocks);
  address += sizeof(customClocks);
}

/**
  Correct any bad values loaded from potentially corrupted EEPROM
*/
static void normaliseLoadedValues(){
  pulseWidth = constrain(pulseWidth, 5, 100);
  
  bpm = constrain(bpm, MIN_BPM, MAX_BPM);
  nextBpm = bpm;
  
  char ct;
  for (byte i=0; i < 4; i++) {
    ct = customClocks[i].clockType;
    if (ct == 'X' || ct == '*' || ct == '/') {
      customClocks[i].clockCount = constrain(customClocks[i].clockCount, 1, 128);
      customClockEnabled[i] = (ct != 'X'); // enable if *, /, or =
    } else {
      // Default the clock to off
      customClocks[i].clockType = 'X';
      customClocks[i].clockCount = 1;
      customClockEnabled[i] = false;
    }
  }
}

//////////////////////////////////////////////////////////////////////
// UI Event handling
//////////////////////////////////////////////////////////////////////
/**
  Select the previous/next function for the custom clock at the given index
*/
static void updateFunction(byte index, int change) {
  String current = F(" X/=*");
  String next    = F("*X/=*X");
  for (byte i = 1; i < 5; i++) {
    if (current[i] == customClocks[index].clockType) {
      customClocks[index].clockType = next[i + change];
      customClockEnabled[index] = customClocks[index].clockType != 'X';

      return;
    }
  }
  customClocks[index].clockType = 'X';
  customClockEnabled[index] = false;
}

/**
  Select the previous/next multiple value for the custom clock at the given index
*/
static void updateFunctionParameter(byte index, int change) {
  byte current[] = {0, 2, 3, 4, 5, 6, 7, 8, 9, 10, 11, 12, 16, 32, 64, 128};
  byte next[] = {128, 2, 3, 4, 5, 6, 7, 8, 9, 10, 11, 12, 16, 32, 64, 128, 2};
  for (byte i = 1; i < 16; i++) {
    if (current[i] == customClocks[index].clockCount) {
      customClocks[index].clockCount = next[i + change];
      return;
    }
  }
  customClocks[index].clockCount = 2;
}

static void allOutputsOff() {
  digitalWrite(CLOCK_PIN, LOW);
  for (byte i=0; i < 4; i++) {
    digitalWrite(CLOCK_PIN, LOW);
  }
}

/**
  Records the timestamps of last 5 rotary encoder movement events, and uses them to determine if we should be scrolling quicker.
  Returns the amount to increment/decrement by
*/
static byte getIncrementFromRotaryUpdateFrequency() {
  static long timestamps[] = {0, 0, 0, 0, 0};
  for (byte i = 0; i < 4; i++) {
    timestamps[i] = timestamps[i + 1];
  }
  timestamps[4] = now;
  if (timestamps[0] != 0 && (timestamps[4] - timestamps[0] < 1000)) {
    // 5+ updates in one second moves to speedy update
    return 10;
  }
  return 1;

}

//////////////////////////////////////////////////////////////////////
// Loop processing for each mode
//////////////////////////////////////////////////////////////////////
/**
  Handles state changes when the state machine is in RUN mode
*/
static void loopRunMode() {
  if (rotaryAStateUpdated){
    if (rotaryAState == PRESSED) {
      byte step = getIncrementFromRotaryUpdateFrequency();
      if (directBpmMode) {
        if (rotaryBState != rotaryAState) { 
          bpm -= step;
        } else {
          bpm += step;
        }
        bpm = constrain(bpm, MIN_BPM, MAX_BPM);
        nextBpm = bpm;
        calculateAllClockDelays();
        updateNextStartTime(true);
        saveEEPROM();
      
      } else {
        if (rotaryBState != rotaryAState) { 
          nextBpm -= step;
        } else {
          nextBpm += step;
        }
        nextBpm = constrain(nextBpm, MIN_BPM, MAX_BPM);
      }
      updateDisplay = true;
    }
  } 

  if (rotaryButtonStateUpdated) {
    if (rotaryButtonState == PRESSED) {
      if (bpm != nextBpm) {
        // Apply the change
        bpm = nextBpm;
        calculateAllClockDelays();
        updateNextStartTime(true);
        saveEEPROM();
        updateDisplay = true;
        LOG(F("BPM"));
      } else {
        // Change to config displayMode
        displayMode = CONFIG;
        // Initialise the config page
        configMode = SELECT_LINE; 
        configLine = A;
        configOption = FUNCTION;
        configOptionSelected = false;
        updateDisplay = true;
        LOG(F("CONFIG"));
      }
    }
  }

  if (resetStateUpdated) {
    if (resetState == PRESSED) {
      tick = 0;
      allOutputsOff();
      updateNextStartTime(true, -1, true);
      updateNextFinishTime(true, -1, true);
      LOG(F("Reset"));
    }
    updateDisplay = true;
  }

  if (runState != lastRunState) {     
    if (runState == PRESSED) {
      // Flips from run to stop or vice versa
      running = !running;
      updateDisplay = true;
      LOG(running ? F("Run") : F("Pause"));
    }
  }
}
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
void loop() {
  // Read current button/rotary encoder state
  rotaryAState = digitalRead(ROTARY_PINA);
  rotaryBState = digitalRead(ROTARY_PINB);
  rotaryButtonState = digitalRead(BUTTON_PIN);
  resetState = digitalRead(RESET_PIN);
  runState = digitalRead(RUN_PIN);

  // Identify changed states
  rotaryAStateUpdated = rotaryAState != lastRotaryAState;
  rotaryButtonStateUpdated = rotaryButtonState != lastRotaryButtonState;
  resetStateUpdated = resetState != lastResetState;
  runStateUpdated = runState != lastRunState;

  // Run the loop handler for the current mode
  if (displayMode == RUN) {
    loopRunMode();
  } else if (displayMode == CONFIG) {
    loopConfigMode();
  } else if (displayMode == TAP) {
    loopTapMode();
  }

  if (updateDisplay) {
    display.clearDisplay();
    // Run the display handler for the current mode
    if (displayMode == RUN) {
      displayRunMode();
    } else if (displayMode == CONFIG) {
      displayConfigMode();
    } else if (displayMode == TAP) {
      displayTapMode();
    }
    
    display.display();
    updateDisplay = false;
  }

  // TODO: Place holder so we can see the input on the unused CLK IN jack
  digitalWrite(CLOCK_IN_LED_PIN, digitalRead(CLOCK_IN_PIN));

  // Store curent button/rotary encoder state to compare against next time
  lastRotaryAState = rotaryAState;
  lastRotaryButtonState = rotaryButtonState;
  lastResetState = resetState;
  lastRunState = runState;
}

//////////////////////////////////////////////////////////////////////
// Interrupt service routine
//////////////////////////////////////////////////////////////////////
ISR(TIMER1_COMPA_vect) {
  // Handler for 1ms timer interrupt
  // Set timeout for next interrupt (1ms)
  OCR1A += 16000; // Advance The COMPA Register
  
  // Look for clock events occuring
  now = millis();
  if (!running || resetState == PRESSED) {
    // We're paused or resetting, move all the event times forward by 1ms, and disable all ouputs
    nextMainClockStart += 1;
    nextMainClockFinish += 1;
    digitalWrite(CLOCK_PIN, LOW);
    for (byte i = 0; i < 4; i++) {
      nextCustomClockStart[i] += 1;
      nextCustomClockFinish[i] += 1;
      digitalWrite(CUSTOM_CLOCK_PINS[i], LOW);
    }

  } else {
    // Normal running mode
    if (now >= nextMainClockStart) {
      // Main clock has triggered
      digitalWrite(CLOCK_PIN, HIGH);
      if (resetState != PRESSED) {
        // Update tick for management of DIVIDED custom clocks
        tick++;
        tick %= 128;
      }
      updateDisplay = true;
      updateNextStartTime();
    }
    for (byte i = 0; i < 4; i++) {
      if (customClockEnabled[i] && now >= nextCustomClockStart[i]) {
        // Custom clock has triggered
        digitalWrite(CUSTOM_CLOCK_PINS[i], HIGH);
        updateNextStartTime(false, i);
      }
    }
      
    if (now >= nextMainClockFinish) {
      // Main clock's pulse has ended
      digitalWrite(CLOCK_PIN, LOW);
      updateNextFinishTime();
    }
    for (byte i=0; i < 4; i++) {
      if (!customClockEnabled[i]) {
        // Clock shouldn't be enabled
        digitalWrite(CLOCK_PIN, LOW);
      } else if (now >= nextCustomClockFinish[i]) {
        // Custom clock's pulse has ended
        digitalWrite(CUSTOM_CLOCK_PINS[i], LOW);
        updateNextFinishTime(false, i);
      }
    }
  }
}

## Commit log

2026-01-27 Initial KiCad commit
    [Eurorack Clock - Panel.kicad_pcb, Eurorack Clock - Panel.kicad_pcb_bom.csv, Eurorack Clock - Panel.kicad_pcb_positions.csv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]
2026-01-27 Added Arduino code
2026-01-27 Added code comments and fixed directory structure
    [Clockipoodle.ino]
2026-01-27 Updated labels on front panel
    [Eurorack Clock - Panel.kicad_pcb]
2026-01-28 Relabeled outputs on schematic and panel, cleaned up pcb layout, removed unused headers, added logo - still need to add to panel
    [Control Panel.kicad_sch, Eurorack Clock - Panel.kicad_pcb, Eurorack Clock.kicad_pcb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]
2026-01-28 Removed overflow bug and removed BPM animation
    [Clockipoodle.ino]
